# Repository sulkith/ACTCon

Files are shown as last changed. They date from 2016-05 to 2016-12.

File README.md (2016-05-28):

# ACTCon
Buttonbox and additional Force Feedback with a Teensy Controller for Assetto Corsa

Currently the Arduino Pro Micro is used. This Chip is much cheaper and sufficient for the Task.
The current State is a Board with an Arduino Pro Micro and two LED Circles with RGB Leds as Dials.
There is an aditional RGB-LED Strip for shift indicator.
Additionaly there is a 1.8' Display which shows informations about:
  - Velocity
  - Engine Speed
  - Current Gear
  - Traction Control
  - Anti Blocking System
  - current lap Time
  - best lap Time

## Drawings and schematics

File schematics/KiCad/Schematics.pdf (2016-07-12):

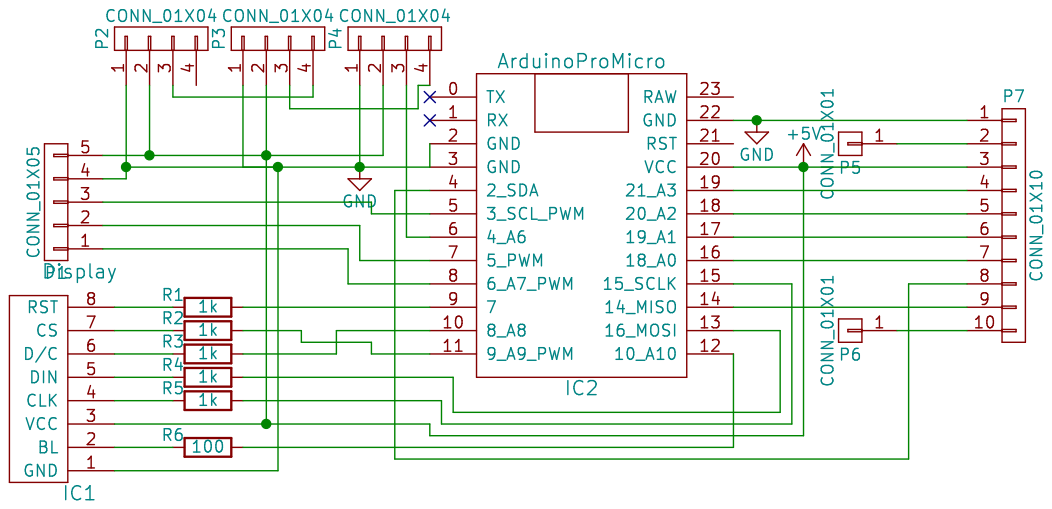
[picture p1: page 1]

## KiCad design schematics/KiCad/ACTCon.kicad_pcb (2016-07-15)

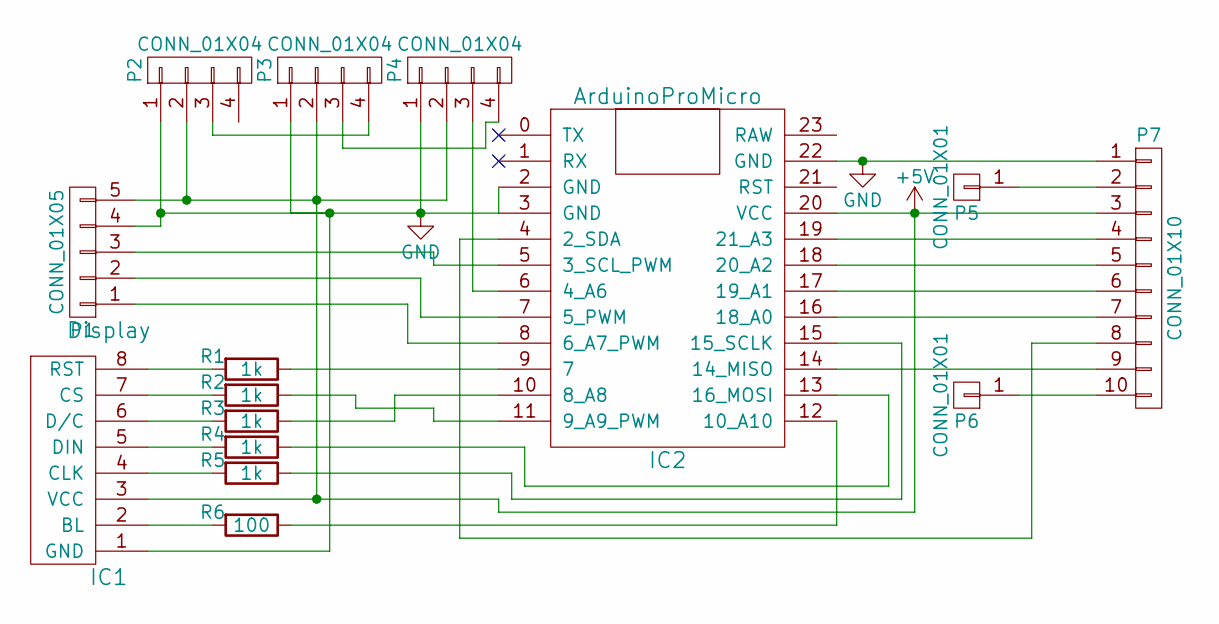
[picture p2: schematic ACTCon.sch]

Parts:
IC1: Display; Pin_Header_Straight_1x08
IC2: ArduinoProMicro
P1: CONN_01X05; Pin_Header_Straight_1x05
P2, P3, P4: CONN_01X04; Pin_Header_Straight_1x04
P5, P6: CONN_01X01; Pin_Header_Straight_1x01
P7: CONN_01X10; Pin_Header_Straight_1x10
R1, R2, R3, R4, R5: 1k; R_0603_HandSoldering
R6: 100; R_0603_HandSoldering

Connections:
+5V: IC1.3 (VCC), IC2.20 (VCC), P1.5, P2.2, P3.2, P4.2, P7.3
GND: IC1.1 (GND), IC2.2 (GND), IC2.3 (GND), IC2.22 (GND), P1.4, P2.1, P3.1, P4.1, P7.1
unnamed: IC1.2 (BL), R6.2
unnamed: IC1.4 (CLK), R5.2
unnamed: IC1.5 (DIN), R4.2
unnamed: IC1.6 (D/C), R3.2
unnamed: IC1.7 (CS), R2.2
unnamed: IC1.8 (RST), R1.2
unnamed: IC2.4 (2_SDA), P7.8
unnamed: IC2.5 (3_SCL_PWM), P1.3
unnamed: IC2.6 (4_A6), P4.3
unnamed: IC2.7 (5_PWM), P1.2
unnamed: IC2.8 (6_A7_PWM), P1.1
unnamed: IC2.9 (7), R1.1
unnamed: IC2.10 (8_A8), R3.1
unnamed: IC2.11 (9_A9_PWM), R2.1
unnamed: IC2.12 (10_A10), R6.1
unnamed: IC2.13 (16_MOSI), R4.1
unnamed: IC2.14 (14_MISO), P7.9
unnamed: IC2.15 (15_SCLK), R5.1
unnamed: IC2.16 (18_A0), P7.7
unnamed: IC2.17 (19_A1), P7.6
unnamed: IC2.18 (20_A2), P7.5
unnamed: IC2.19 (21_A3), P7.4
unnamed: P2.3, P3.4
unnamed: P3.3, P4.4
unnamed: P5.1, P7.2
unnamed: P6.1, P7.10

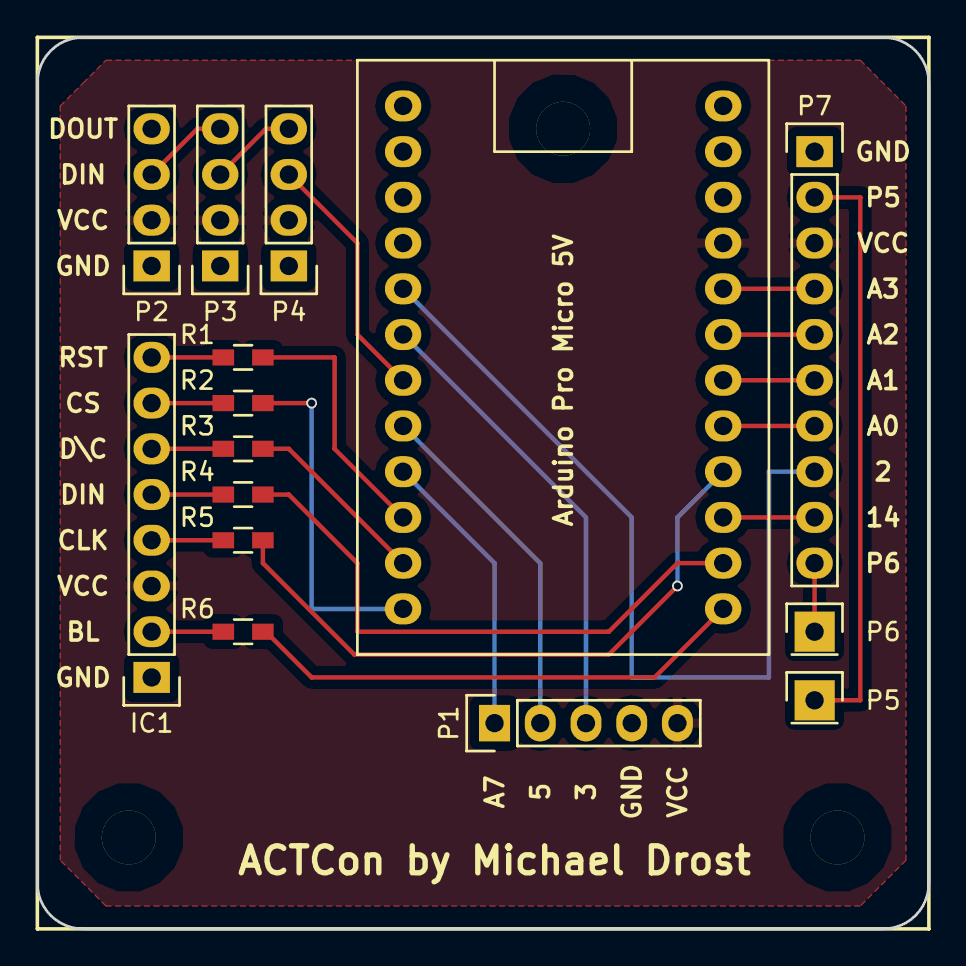
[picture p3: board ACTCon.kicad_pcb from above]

Board: 2 copper layers, 49.5 x 49.5 mm, 15 parts (0 on the bottom side), 28 nets.

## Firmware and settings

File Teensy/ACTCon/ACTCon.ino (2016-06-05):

/*
 * The MIT License (MIT)
 *
 * Copyright (c) 2015 Michael Drost
 *
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
 * THE SOFTWARE IS PROVIDED "AS IS", WITHOUT WARRANTY OF ANY KIND, EXPRESS OR
 * IMPLIED, INCLUDING BUT NOT LIMITED TO THE WARRANTIES OF MERCHANTABILITY,
 * FITNESS FOR A PARTICULAR PURPOSE AND NONINFRINGEMENT. IN NO EVENT SHALL THE
 * AUTHORS OR COPYRIGHT HOLDERS BE LIABLE FOR ANY CLAIM, DAMAGES OR OTHER
 * LIABILITY, WHETHER IN AN ACTION OF CONTRACT, TORT OR OTHERWISE, ARISING FROM,
 * OUT OF OR IN CONNECTION WITH THE SOFTWARE OR THE USE OR OTHER DEALINGS IN THE
 * SOFTWARE.
 */

#include <FastLED.h>
#include <TFT.h>  // Arduino LCD library
#include <SPI.h>
//#include <usb_keyboard.h>
#include "globals.h"
#include "config.h"
#include "pinning.h"
#include "util.h"
#include "SerialConf.h"
#include "SerialComStack.h"
#include "SignalConversions.h"
#include "ForceFeedback.h"
#include "rpm.h"
#include "WS2812.h"
#include "ST7753_Display.h"
#include "actionScheduler.h"
#include "keyboardOutput.h"
#include "digitalInput.h"
#include "startupTest.h"
#include "t15sim.h"



// Information about the LED strip itself


void setup()
{
  SerialComStack_ini();
  SignalConversion_ini();
  ForceFeedback_ini();
  T15Sim_ini();
  rpm_ini();
  WS2812_ini();
  ST7735_Display_ini();
  actionScheduler_ini();
  startupTest_ini();
  
}

void reIniSystem()
{
  SerialComStack_ReIni();
  SignalConversion_ini();
  ForceFeedback_ini();
  rpm_ini();
  WS2812_ini();
  ST7735_Display_cyclic(); // Cyclic Task is called to not redraw everything on the Display only the new Data
  keyboardOutput_ini();
  digitalInput_ini();
  actionScheduler_ini();
}


void loop()
{
  static int ctr = 0;
  ctr++;
  SerialComStack_cyclic();
  startupTest_cyclic();
  if (ctr % 1 == 0)
  {
    T15Sim_cyclic();
    SignalConversion();
    ForceFeedback_cyclic();
    rpm_cyclic();
    WS2812_cyclic();
    ST7735_Display_cyclic();

  }
  digitalInput_cyclic();
  actionScheduler_cyclic();
}

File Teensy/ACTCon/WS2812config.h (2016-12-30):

/*
 * The MIT License (MIT)
 *
 * Copyright (c) 2015 Michael Drost
 *
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
 * THE SOFTWARE IS PROVIDED "AS IS", WITHOUT WARRANTY OF ANY KIND, EXPRESS OR
 * IMPLIED, INCLUDING BUT NOT LIMITED TO THE WARRANTIES OF MERCHANTABILITY,
 * FITNESS FOR A PARTICULAR PURPOSE AND NONINFRINGEMENT. IN NO EVENT SHALL THE
 * AUTHORS OR COPYRIGHT HOLDERS BE LIABLE FOR ANY CLAIM, DAMAGES OR OTHER
 * LIABILITY, WHETHER IN AN ACTION OF CONTRACT, TORT OR OTHERWISE, ARISING FROM,
 * OUT OF OR IN CONNECTION WITH THE SOFTWARE OR THE USE OR OTHER DEALINGS IN THE
 * SOFTWARE.
 */
//#define FORCE_FEEDBACK

#define RPM_LED_DISPLAY

#define WS2812_DIPLAY
#define WS2812_NUM_LEDS    24+24+8
#define WS2812_BRIGHTNESS  255
#define WS2812_LOWEST_LED_PERC 80
#define WS2812_HIGHEST_LED_PERC 98

#define WS2812_WHITE 0x202020
#define WS2812_GREEN 0x002000
#define WS2812_YELLOW 0x202000
#define WS2812_RED 0x301000
#define WS2812_BRIGHT_RED CRGB::Red
#define WS2812_BLUE 0x000020
//CRGB WS2812_LED_COLORS[WS2812_NUM_LEDS] =      {CRGB::White,WS2812_GREEN,WS2812_GREEN,WS2812_YELLOW,WS2812_YELLOW,WS2812_RED,WS2812_RED,WS2812_RED};
//int WS2812_LED_ACTIVE_POINT[WS2812_NUM_LEDS] = {650,        700,        750,        800,         850,         900,      950,      980};

#define CONFIG_H_WS2812_CompareType_t
#include "configTypes.h"

enum WS2812_inputValue_t
{
  //remember to add value in the WS2812_getValue function too!!!
  WS2812_getValue_enum(rpmprc10)
  WS2812_getValue_enum(rpm)
  WS2812_getValue_enum(vfzg)
  WS2812_getValue_enum(gVertical)
  WS2812_getValue_enum(gFrontal)
  dummy
};

int WS2812_getValue(enum WS2812_inputValue_t valueKey)
{
  switch (valueKey)
  {
      WS2812_getValue_case(rpmprc10)
      WS2812_getValue_case(rpm)
      WS2812_getValue_case(vfzg)
    case idgVertical:
      return gForce[gForceIdxVertical];
    case idgFrontal:
      return gForce[gForceIdxFrontal];
    default:
      return -1;
  }
  return 0;
}

#define START_LED_STRIP1 48
#define START_LED_DIAL1 0
#define START_LED_DIAL2 24

#define CONFIG_H_WS2812_Action_t
#include "configTypes.h"
/*Valid Compares are less, less_equal, equal, more_equal, more, not_equal, always_true*/
/*Pay Attention. the Actions a checked from first to last. later Actions override previous ones*/
WS2812_Action_t WS2812_Actions[] =
{ 
  ACTION_NR_COLOR_COMPARE_INPUTVALUE_COMPAREVALUE(START_LED_STRIP1 + 0, WS2812_GREEN, more_equal, rpmprc10, 650)
  ACTION_NR_COLOR_COMPARE_INPUTVALUE_COMPAREVALUE(START_LED_STRIP1 + 1, WS2812_GREEN, more_equal, rpmprc10, 700)
  ACTION_NR_COLOR_COMPARE_INPUTVALUE_COMPAREVALUE(START_LED_STRIP1 + 2, WS2812_YELLOW, more_equal, rpmprc10, 750)
  ACTION_NR_COLOR_COMPARE_INPUTVALUE_COMPAREVALUE(START_LED_STRIP1 + 3, WS2812_YELLOW, more_equal, rpmprc10, 800)
  ACTION_NR_COLOR_COMPARE_INPUTVALUE_COMPAREVALUE(START_LED_STRIP1 + 4, WS2812_RED, more_equal, rpmprc10, 850)
  ACTION_NR_COLOR_COMPARE_INPUTVALUE_COMPAREVALUE(START_LED_STRIP1 + 5, WS2812_RED, more_equal, rpmprc10, 900)
  ACTION_NR_COLOR_COMPARE_INPUTVALUE_COMPAREVALUE(START_LED_STRIP1 + 6, WS2812_BRIGHT_RED, more_equal, rpmprc10, 950)
  ACTION_NR_COLOR_COMPARE_INPUTVALUE_COMPAREVALUE(START_LED_STRIP1 + 7, WS2812_BRIGHT_RED, more_equal, rpmprc10, 950)
  
  ACTION_NR_COLOR_COMPARE_INPUTVALUE_COMPAREVALUE(START_LED_STRIP1 + 0, WS2812_BRIGHT_RED, more_equal, rpmprc10, 950)
  ACTION_NR_COLOR_COMPARE_INPUTVALUE_COMPAREVALUE(START_LED_STRIP1 + 1, WS2812_BRIGHT_RED, more_equal, rpmprc10, 950)
  ACTION_NR_COLOR_COMPARE_INPUTVALUE_COMPAREVALUE(START_LED_STRIP1 + 2, WS2812_BRIGHT_RED, more_equal, rpmprc10, 950)
  ACTION_NR_COLOR_COMPARE_INPUTVALUE_COMPAREVALUE(START_LED_STRIP1 + 3, WS2812_BRIGHT_RED, more_equal, rpmprc10, 950)
  ACTION_NR_COLOR_COMPARE_INPUTVALUE_COMPAREVALUE(START_LED_STRIP1 + 4, WS2812_BRIGHT_RED, more_equal, rpmprc10, 950)
  ACTION_NR_COLOR_COMPARE_INPUTVALUE_COMPAREVALUE(START_LED_STRIP1 + 5, WS2812_BRIGHT_RED, more_equal, rpmprc10, 950)
  ACTION_NR_COLOR_COMPARE_INPUTVALUE_COMPAREVALUE(START_LED_STRIP1 + 6, WS2812_BRIGHT_RED, more_equal, rpmprc10, 950)
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

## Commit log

2015-12-20 Added Schematic
    [Version1_onlyMotor.fzz]
2015-12-20 Added Sample For Button Press forwarding with Bounce Class. Works in Assetto Corsa for Traction Control
    schematics/Version2_WithButton.fzz can be used for this sample. But disable the Vibration motor first since it is not disabled by the sketch
    [Version2_WithButton.fzz]
2016-01-16 Added a WS2812 LED Strip for the RPM. Softwar is also compatible with a Sparkfun Pro Micro now. The Sparkfun chip is only working with the new Host Application from the last commit.
2016-01-18 Added Project Structure for the Teensy Program. Reinvented the Serial Communication. Added Configuration File.
    Needed some Changes on the PC SW to get the Communication working.
2016-01-24 Modified Receiving. It spawns a new Thread now. This reduces the latency significantly!. Needs Cleanup ;-)
2016-01-24 Working on Pro Micro. Not on the Teensy -.-
2016-01-24 Added Current and last Lap Time
2016-02-07 Increased led Brightness
2016-02-07 Filter for maxrpm. Maxrpm is now only measured in N
2016-02-07 Restructured an refactored the code For the WS2812 LEDs. Now it is possible to use an LED in different Colors for different applications.
2016-02-21 Added the ability of using inputs as keyboard presses. Added a reini section to reinitialize the system. e.g. maxrpm etc. some Cleanup: removed the old led blinking pin for maxrpm.
2016-02-21 Added Pin to reset the saved Values and tested it. PIN6 now has to be pulled to VCC to keep the controller from resetting unintentionally.
2016-05-27 some reconfigurations for the soldered Board
2016-05-28 Fixed Pullup Functionality in the digital Input Function
    [digitalInput.h]
2016-05-28 Adapted to new Board. added second Dial.
2016-06-05 Added Buttonbox
2016-06-05 Added T15Simulation via a Key-Switch :-)
2016-06-05 Fixed maxrpm after startup test
    [rpm.h]
2016-07-05 Fixed a Bug in startupTest.h Endless loop while switching on off while on hold
2016-07-07 Added schematics with KiCad. on a 5cmX5cm PCB which should be possible to produce with dirtypcbs on the cheap :-)
    [ACTCon.kicad_pcb, ACTCon.sch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]
2016-07-11 Updated schematics. Added Drill gerber and corrected the padsize for the arduino.
    [ACTCon.kicad_pcb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]
2016-07-12 moved the wires around the connectors.
    [ACTCon.kicad_pcb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]
2016-07-15 Moved PCB description
    [ACTCon.kicad_pcb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]
2016-12-30 decreased led brightness
